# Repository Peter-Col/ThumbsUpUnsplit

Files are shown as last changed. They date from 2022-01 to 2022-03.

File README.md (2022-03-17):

# ThumbsUpUnsplit
 Multilevel 44 Key Ergonomic Keyboard
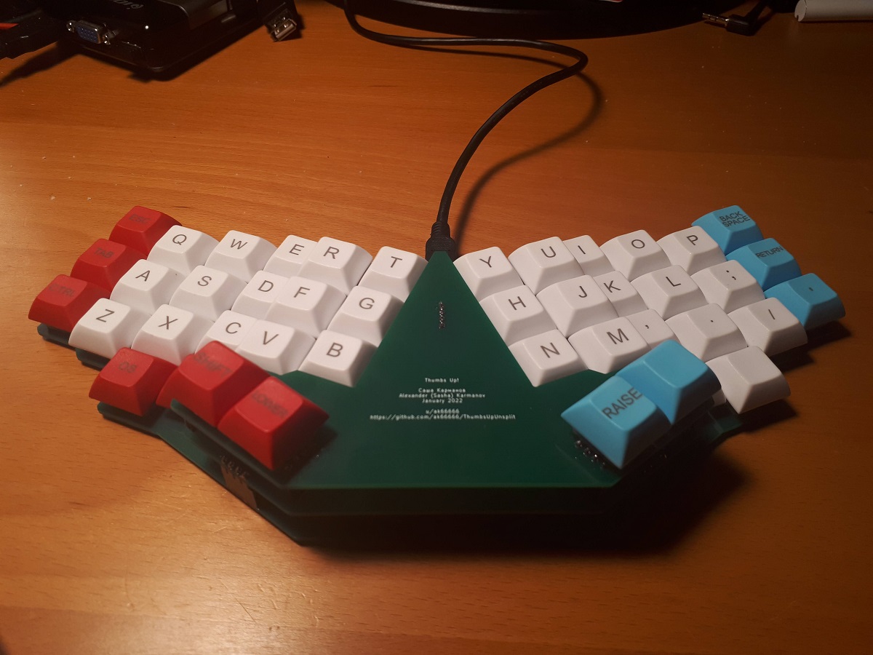
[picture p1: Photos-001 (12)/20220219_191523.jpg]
Main view

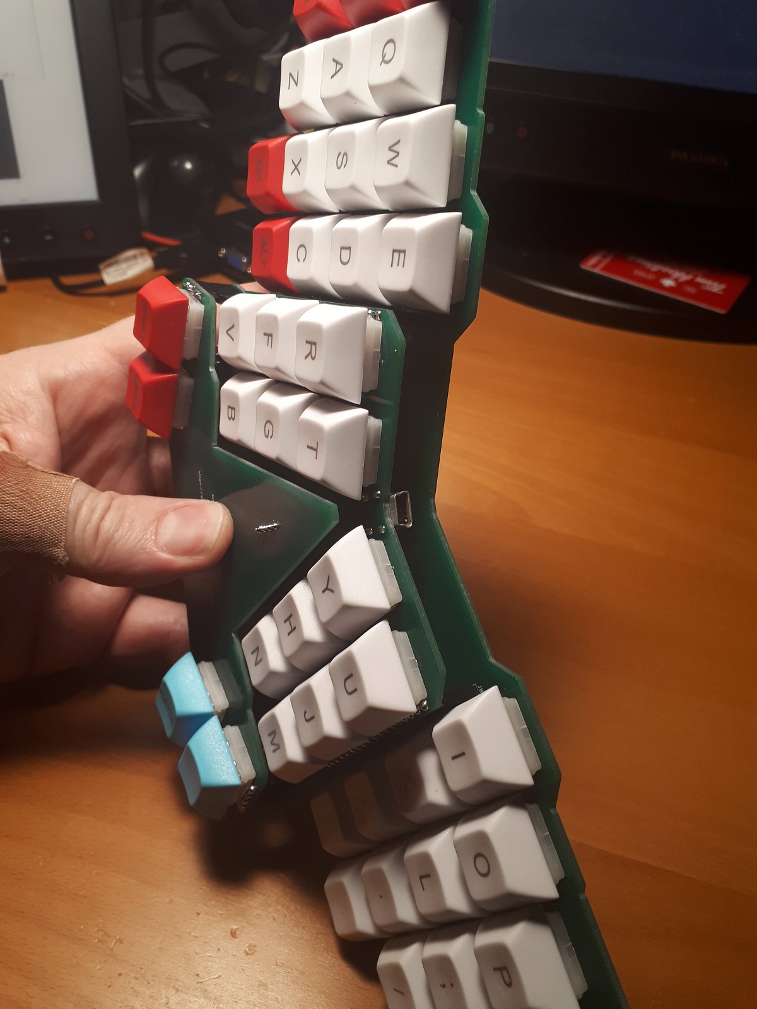
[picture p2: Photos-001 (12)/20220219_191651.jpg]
Three levels are visible

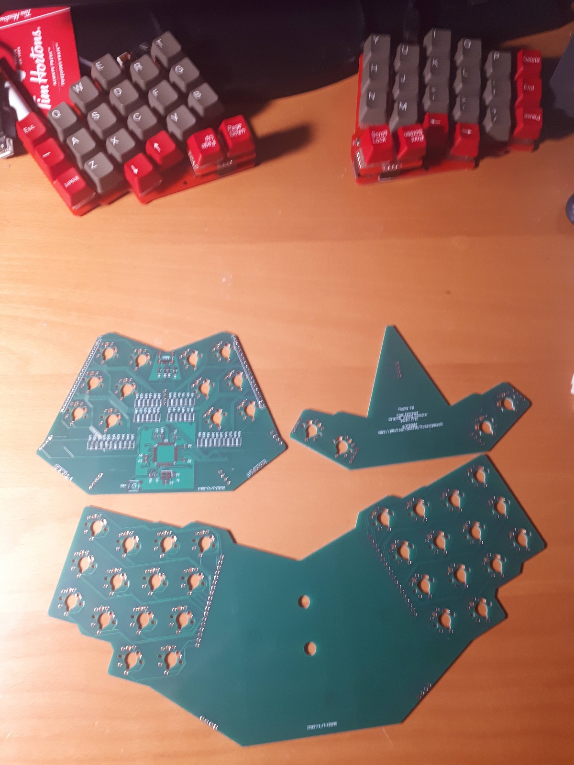
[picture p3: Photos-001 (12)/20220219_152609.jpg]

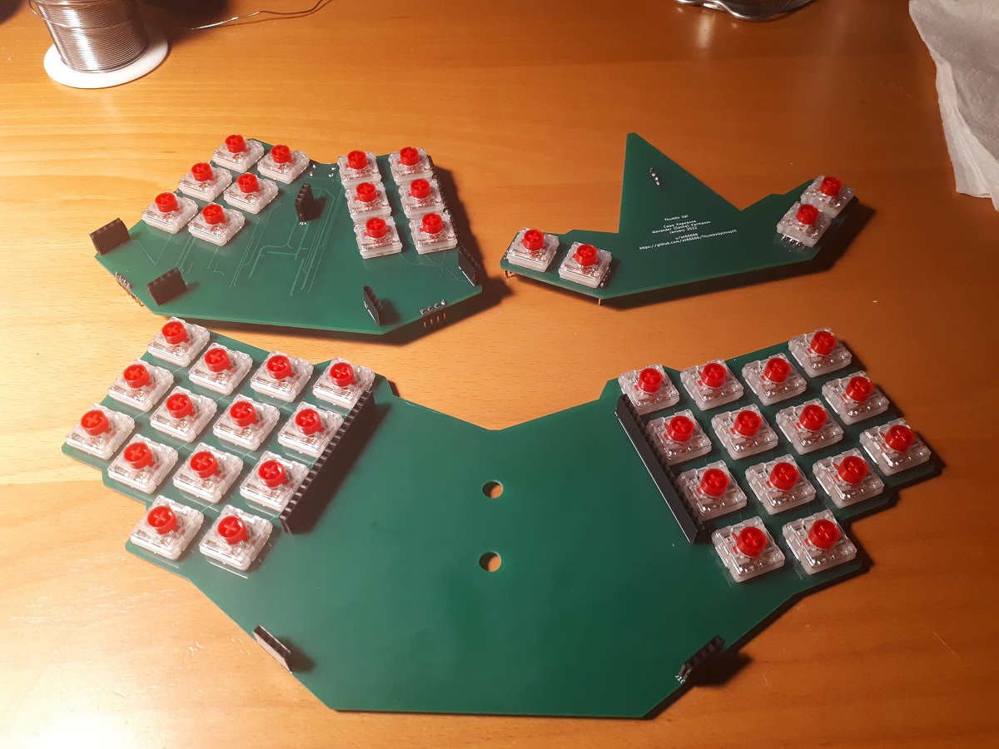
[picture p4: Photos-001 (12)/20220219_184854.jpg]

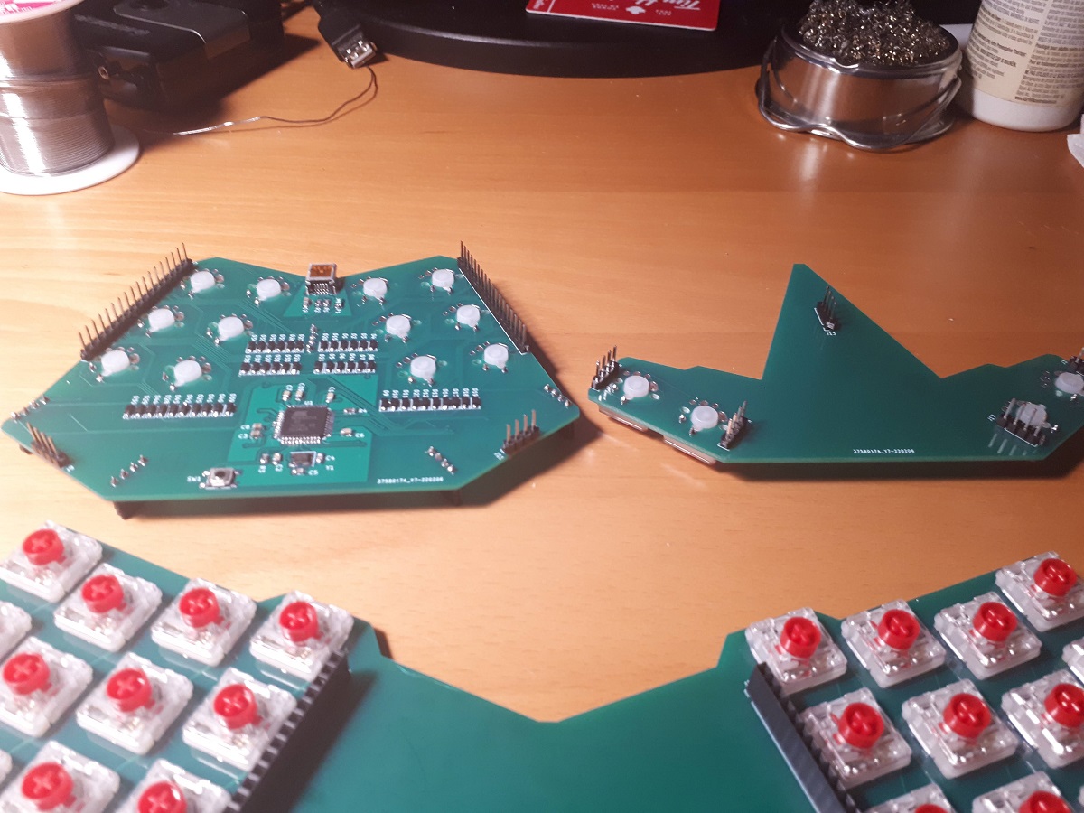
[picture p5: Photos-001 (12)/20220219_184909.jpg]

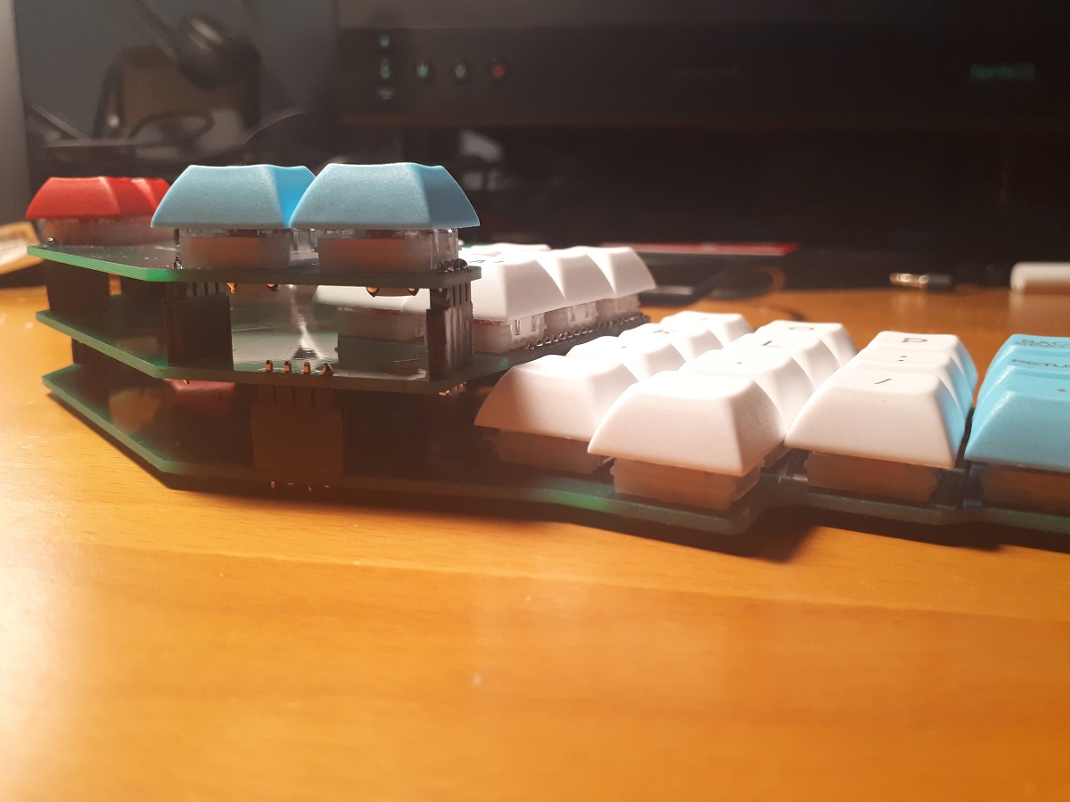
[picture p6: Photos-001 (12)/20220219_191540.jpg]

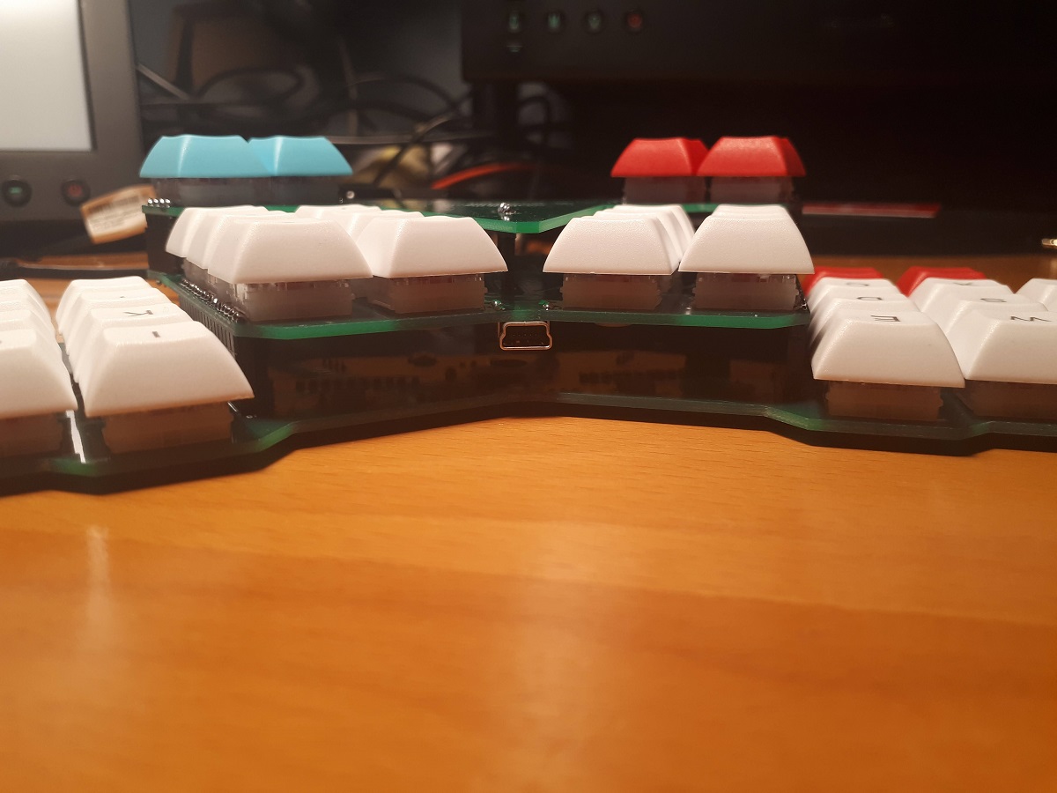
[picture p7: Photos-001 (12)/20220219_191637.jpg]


# Firmware

The board was supposed to use Planck rev4 software.
But I made a mistake in schema and mirrored the columns.
To make it work - modify \qmk_firmware\keyboards\planck\config.h, replace the pin definition with this one:

#define MATRIX_COL_PINS { D7, B4, D6, D4, F7, F6, F5, F4, C7, B0, F0, F1 }

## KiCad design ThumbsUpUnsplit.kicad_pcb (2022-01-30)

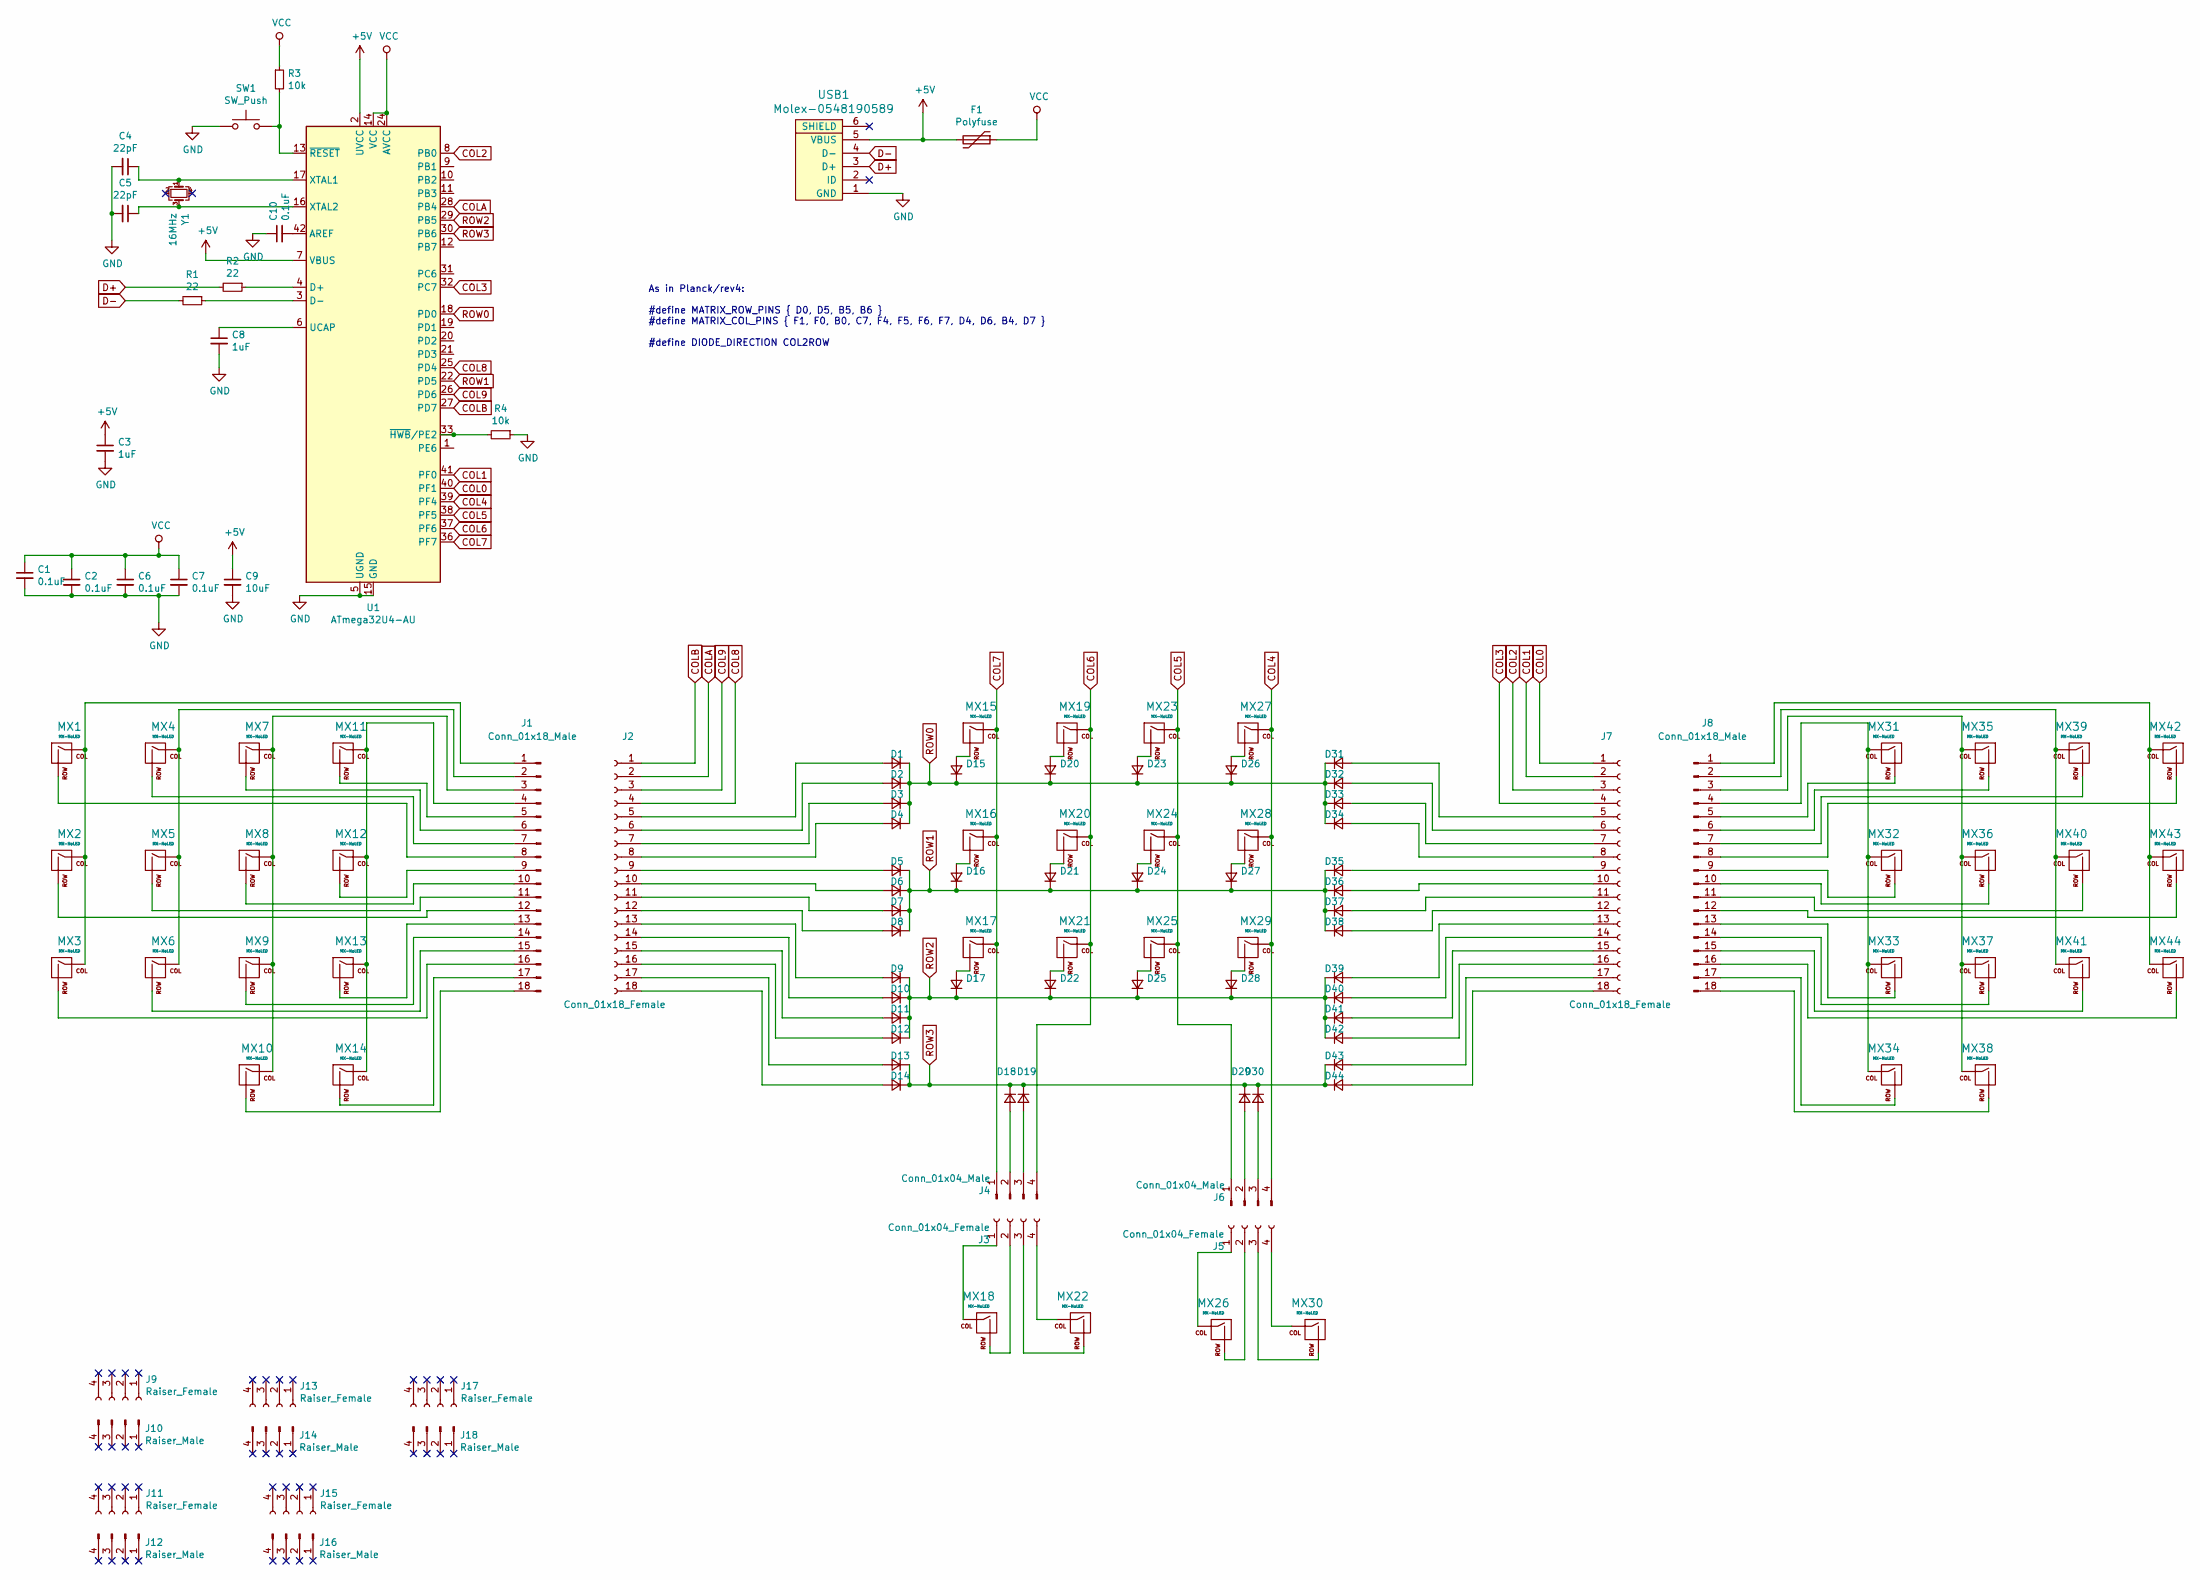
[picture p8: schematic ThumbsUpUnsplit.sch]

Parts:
C1, C2, C6, C7, C10: 0.1uF; C_0805_2012Metric
C3, C8: 1uF; C_0805_2012Metric
C4, C5: 22pF; C_0805_2012Metric
C9: 10uF; C_0805_2012Metric
D1, D2, D3, D4, D5, D6, D7, D8, D9, D10, D11, D12, D13, D14, D15, D16, D17, D18, D19, D20, D21, D22, D23, D24, D25, D26, D27, D28, D29, D30, D31, D32, D33, D34, D35, D36, D37, D38, D39, D40, D41, D42, D43, D44: D_Small; D_SOD-123
F1: Polyfuse; Fuse_1206_3216Metric
J1, J8: Conn_01x18_Male; PinHeader_1x18_P2.54mm_Vertical
J2, J7: Conn_01x18_Female; PinSocket_1x18_P2.54mm_Vertical
J3, J5: Conn_01x04_Female; PinSocket_1x04_P2.54mm_Vertical
J4, J6: Conn_01x04_Male; PinHeader_1x04_P2.54mm_Vertical
J9, J11, J13, J15, J17: Raiser_Female; PinSocket_1x04_P2.54mm_Vertical
J10, J12, J14, J16, J18: Raiser_Male; PinHeader_1x04_P2.54mm_Vertical
MX1, MX2, MX3, MX4, MX5, MX6, MX7, MX8, MX9, MX10, MX11, MX12, MX13, MX14, MX15, MX16, MX17, MX18, MX19, MX20, MX21, MX22, MX23, MX24, MX25, MX26, MX27, MX28, MX29, MX30, MX31, MX32, MX33, MX34, MX35, MX36, MX37, MX38, MX39, MX40, MX41, MX42, MX43, MX44: MX-NoLED; MX-Alps-Choc-KS32-X-1U-NoLED
R1, R2: 22; R_0805_2012Metric
R3, R4: 10k; R_0805_2012Metric
SW1: SW_Push; SKQG-1155865
U1: ATmega32U4-AU; TQFP-44_10x10mm_P0.8mm
USB1: Molex-0548190589
Y1: 16MHz; Crystal_SMD_3225-4Pin_3.2x2.5mm_HandSoldering

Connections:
+5V: C3.1, C9.1, F1.2, U1.2 (UVCC), U1.7 (VBUS), USB1.5 (VBUS)
COL0: J7.1, U1.40 (PF1)
COL1: J7.2, U1.41 (PF0)
COL2: J7.3, U1.8 (PB0)
COL3: J7.4, U1.32 (PC7)
COL4: J6.4, MX27.1 (COL), MX28.1 (COL), MX29.1 (COL), U1.39 (PF4)
COL5: J6.1, MX23.1 (COL), MX24.1 (COL), MX25.1 (COL), U1.38 (PF5)
COL6: J4.4, MX19.1 (COL), MX20.1 (COL), MX21.1 (COL), U1.37 (PF6)
COL7: J4.1, MX15.1 (COL), MX16.1 (COL), MX17.1 (COL), U1.36 (PF7)
COL8: J2.4, U1.25 (PD4)
COL9: J2.3, U1.26 (PD6)
COLA: J2.2, U1.28 (PB4)
COLB: J2.1, U1.27 (PD7)
D+: R2.2, USB1.3 (D+)
D-: R1.2, USB1.4 (D-)
GND: C1.2, C2.2, C3.2, C4.2, C5.2, C6.2, C7.2, C8.2, C9.2, C10.1, R4.1, SW1.1, U1.5 (UGND), U1.15 (GND), U1.23 (GND), U1.35 (GND), U1.43 (GND), USB1.1 (GND)
unnamed: C4.1, U1.17 (XTAL1), Y1.1
unnamed: C5.1, U1.16 (XTAL2), Y1.3
unnamed: C8.1, U1.6 (UCAP)
unnamed: C10.2, U1.42 (AREF)
unnamed: D1.2 (A), J2.5
unnamed: D2.2 (A), J2.6
unnamed: D3.2 (A), J2.7
unnamed: D4.2 (A), J2.8
unnamed: D5.2 (A), J2.9
unnamed: D6.2 (A), J2.10
unnamed: D7.2 (A), J2.11
unnamed: D8.2 (A), J2.12
unnamed: D9.2 (A), J2.13
unnamed: D10.2 (A), J2.14
unnamed: D11.2 (A), J2.15
unnamed: D12.2 (A), J2.16
unnamed: D13.2 (A), J2.17
unnamed: D14.2 (A), J2.18
unnamed: D15.2 (A), MX15.2 (ROW)
unnamed: D16.2 (A), MX16.2 (ROW)
unnamed: D17.2 (A), MX17.2 (ROW)
unnamed: D18.2 (A), J4.2
unnamed: D19.2 (A), J4.3
unnamed: D20.2 (A), MX19.2 (ROW)
unnamed: D21.2 (A), MX20.2 (ROW)
unnamed: D22.2 (A), MX21.2 (ROW)
unnamed: D23.2 (A), MX23.2 (ROW)
unnamed: D24.2 (A), MX24.2 (ROW)
unnamed: D25.2 (A), MX25.2 (ROW)
unnamed: D26.2 (A), MX27.2 (ROW)
unnamed: D27.2 (A), MX28.2 (ROW)
unnamed: D28.2 (A), MX29.2 (ROW)
unnamed: D29.2 (A), J6.2
unnamed: D30.2 (A), J6.3
unnamed: D31.2 (A), J7.5
unnamed: D32.2 (A), J7.6
unnamed: D33.2 (A), J7.7
unnamed: D34.2 (A), J7.8
unnamed: D35.2 (A), J7.9
unnamed: D36.2 (A), J7.10
unnamed: D37.2 (A), J7.11
unnamed: D38.2 (A), J7.12
unnamed: D39.2 (A), J7.13
unnamed: D40.2 (A), J7.14
unnamed: D41.2 (A), J7.15
unnamed: D42.2 (A), J7.16
unnamed: D43.2 (A), J7.17
unnamed: D44.2 (A), J7.18
unnamed: J1.1, MX1.1 (COL), MX2.1 (COL), MX3.1 (COL)
unnamed: J1.2, MX4.1 (COL), MX5.1 (COL), MX6.1 (COL)
unnamed: J1.3, MX7.1 (COL), MX8.1 (COL), MX9.1 (COL), MX10.1 (COL)
unnamed: J1.4, MX11.1 (COL), MX12.1 (COL), MX13.1 (COL), MX14.1 (COL)
unnamed: J1.5, MX11.2 (ROW)
unnamed: J1.6, MX7.2 (ROW)
unnamed: J1.7, MX4.2 (ROW)
unnamed: J1.8, MX1.2 (ROW)
unnamed: J1.9, MX12.2 (ROW)
unnamed: J1.10, MX8.2 (ROW)
unnamed: J1.11, MX5.2 (ROW)
unnamed: J1.12, MX2.2 (ROW)
unnamed: J1.13, MX13.2 (ROW)
unnamed: J1.14, MX9.2 (ROW)
unnamed: J1.15, MX6.2 (ROW)
unnamed: J1.16, MX3.2 (ROW)
unnamed: J1.17, MX14.2 (ROW)
unnamed: J1.18, MX10.2 (ROW)
unnamed: J3.1, MX18.1 (COL)
unnamed: J3.2, MX18.2 (ROW)
unnamed: J3.3, MX22.2 (ROW)
unnamed: J3.4, MX22.1 (COL)
unnamed: J5.1, MX26.1 (COL)
unnamed: J5.2, MX26.2 (ROW)
unnamed: J5.3, MX30.2 (ROW)
unnamed: J5.4, MX30.1 (COL)
unnamed: J8.1, MX42.1 (COL), MX43.1 (COL), MX44.1 (COL)
unnamed: J8.2, MX39.1 (COL), MX40.1 (COL), MX41.1 (COL)
unnamed: J8.3, MX35.1 (COL), MX36.1 (COL), MX37.1 (COL), MX38.1 (COL)
unnamed: J8.4, MX31.1 (COL), MX32.1 (COL), MX33.1 (COL), MX34.1 (COL)
unnamed: J8.5, MX31.2 (ROW)
unnamed: J8.6, MX35.2 (ROW)
unnamed: J8.7, MX39.2 (ROW)
unnamed: J8.8, MX42.2 (ROW)
unnamed: J8.9, MX32.2 (ROW)
unnamed: J8.10, MX36.2 (ROW)
unnamed: J8.11, MX40.2 (ROW)
unnamed: J8.12, MX43.2 (ROW)
unnamed: J8.13, MX33.2 (ROW)
unnamed: J8.14, MX37.2 (ROW)
unnamed: J8.15, MX41.2 (ROW)
unnamed: J8.16, MX44.2 (ROW)
unnamed: J8.17, MX34.2 (ROW)
unnamed: J8.18, MX38.2 (ROW)
unnamed: R1.1, U1.3 (D-)
unnamed: R2.1, U1.4 (D+)
unnamed: R3.2, SW1.2, U1.13 (~RESET)
unnamed: R4.2, U1.33 (~HWB~/PE2)
ROW0: D1.1 (K), D2.1 (K), D3.1 (K), D4.1 (K), D15.1 (K), D20.1 (K), D23.1 (K), D26.1 (K), D31.1 (K), D32.1 (K), D33.1 (K), D34.1 (K), U1.18 (PD0)
ROW1: D5.1 (K), D6.1 (K), D7.1 (K), D8.1 (K), D16.1 (K), D21.1 (K), D24.1 (K), D27.1 (K), D35.1 (K), D36.1 (K), D37.1 (K), D38.1 (K), U1.22 (PD5)
ROW2: D9.1 (K), D10.1 (K), D11.1 (K), D12.1 (K), D17.1 (K), D22.1 (K), D25.1 (K), D28.1 (K), D39.1 (K), D40.1 (K), D41.1 (K), D42.1 (K), U1.29 (PB5)
ROW3: D13.1 (K), D14.1 (K), D18.1 (K), D19.1 (K), D29.1 (K), D30.1 (K), D43.1 (K), D44.1 (K), U1.30 (PB6)
VCC: C1.1, C2.1, C6.1, C7.1, F1.1, R3.1, U1.14 (VCC), U1.24 (AVCC), U1.34 (VCC), U1.44 (AVCC)

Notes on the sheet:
As in Planck/rev4: #define MATRIX_ROW_PINS { D0, D5, B5, B6 } #define MATRIX_COL_PINS { F1, F0, B0, C7, F4, F5, F6, F7, D4, D6, B4, D7 } #define DIODE_DIRECTION COL2ROW

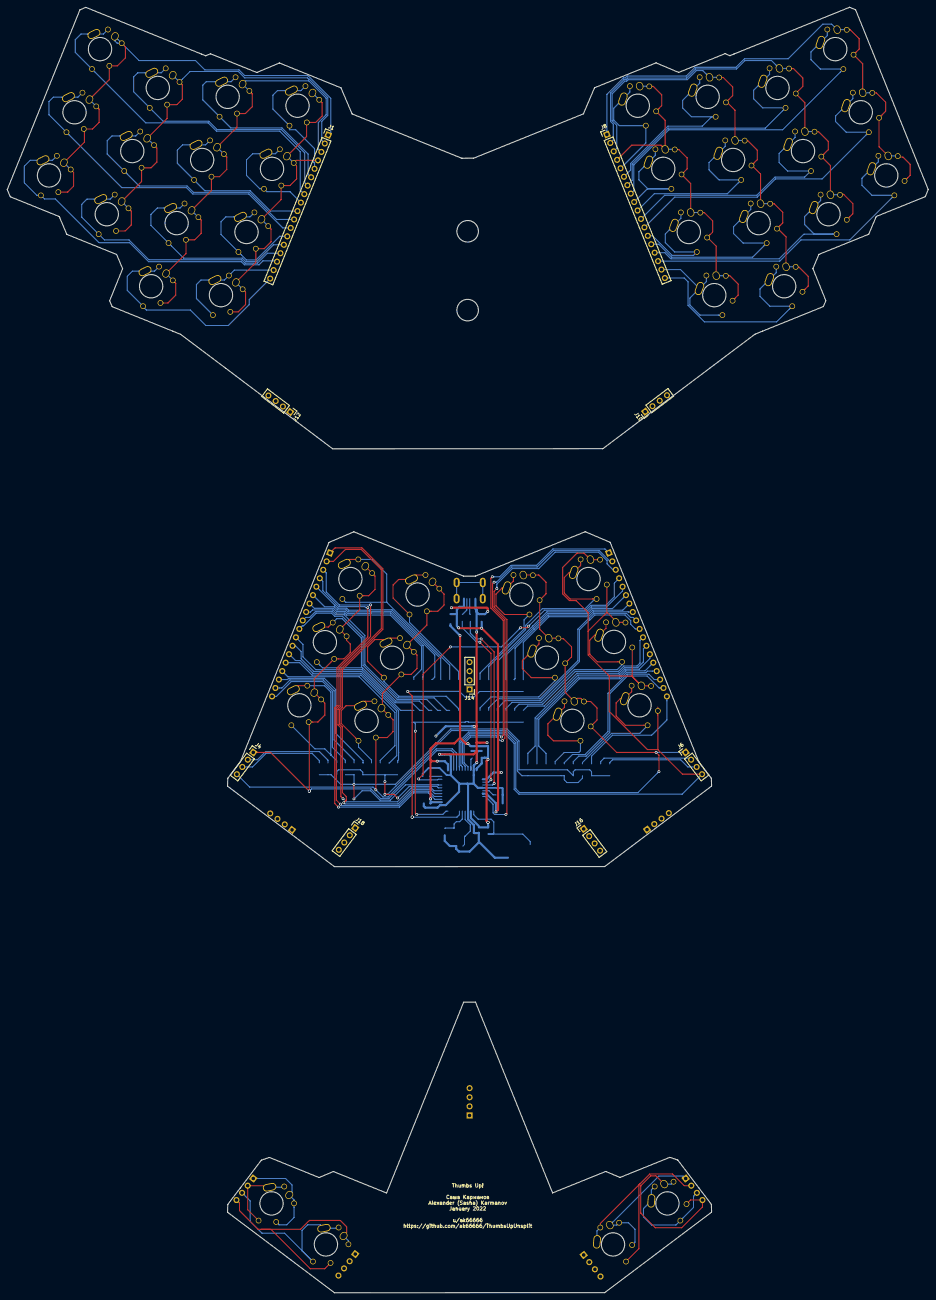
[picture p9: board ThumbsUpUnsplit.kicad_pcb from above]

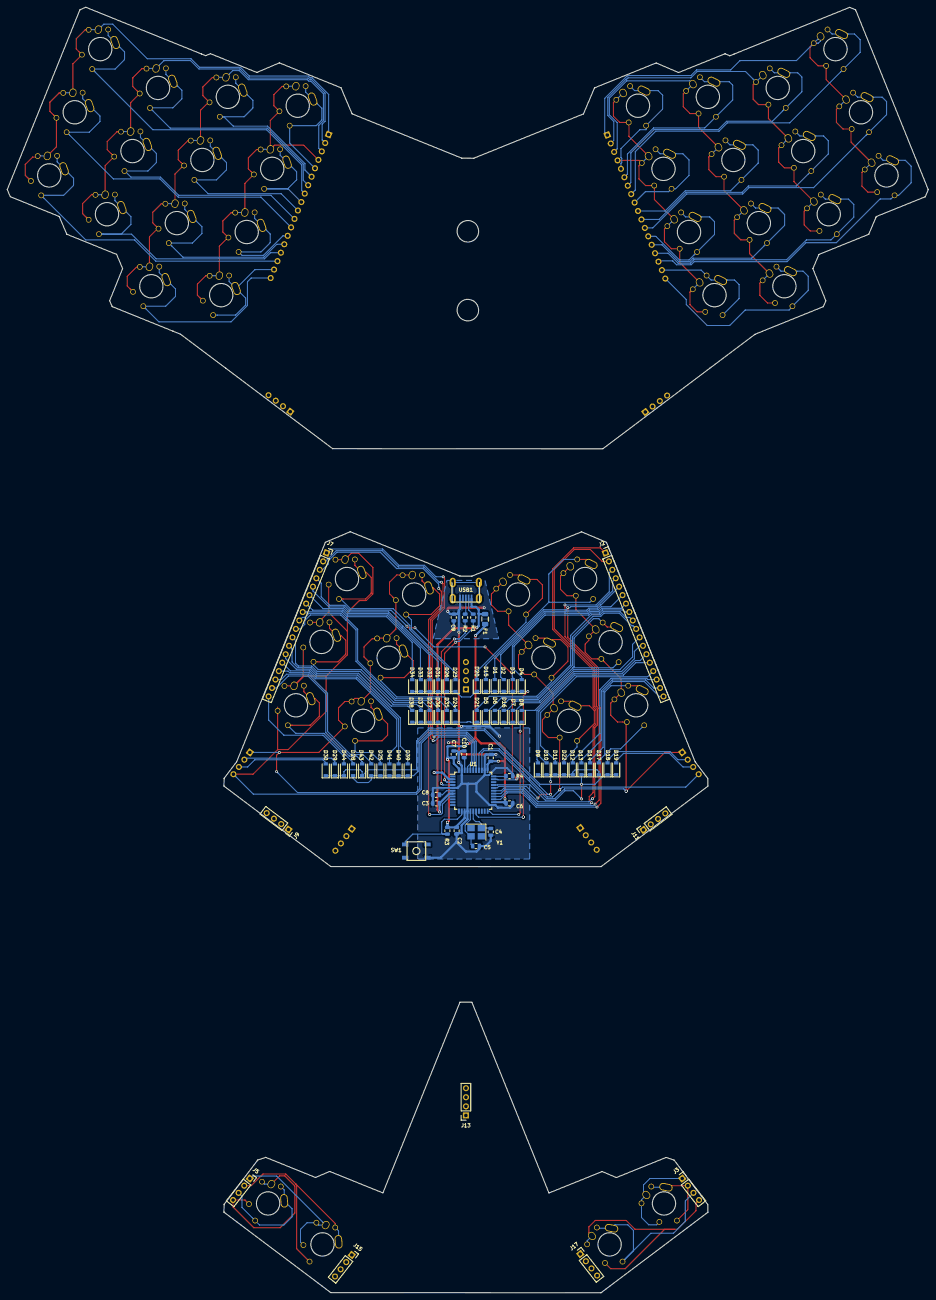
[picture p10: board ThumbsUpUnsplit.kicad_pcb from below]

Board: 2 copper layers, 256.9 x 358.6 mm, 125 parts (72 on the bottom side), 117 nets.

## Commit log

2022-01-27 Project created
    [ThumbsUpUnsplit.kicad_pcb, ThumbsUpUnsplit.sch]
2022-01-27 Laid out the matrix
    [ThumbsUpUnsplit.sch]
2022-01-28 Layed out the switches and edge cuts
    [ThumbsUpUnsplit.sch]
2022-01-28 Roughed in the connectors
    [ThumbsUpUnsplit.kicad_pcb, ThumbsUpUnsplit.sch]
2022-01-29 Bottom plate routed
    [ThumbsUpUnsplit.kicad_pcb, ThumbsUpUnsplit.sch]
2022-01-29 Left side roughed in
    [ThumbsUpUnsplit.kicad_pcb, ThumbsUpUnsplit.sch]
2022-01-30 Laid out, ready for the pre-order inspection
    [ThumbsUpUnsplit-B_Cu.gbl, ThumbsUpUnsplit-B_Cu.gbr, ThumbsUpUnsplit-B_Mask.gbr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]
